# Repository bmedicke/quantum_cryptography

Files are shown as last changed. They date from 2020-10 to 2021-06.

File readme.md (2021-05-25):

quantum cryptography logo

Demonstration of **quantum-cryptography-based one-time pad communication** via<br>the **BB84 algorithm** using a non-single photon source.



[project progress](#project-progress) | [contributors](#contributors) | [repository structure](#repository-structure) | [frequently asked questions](#frequently-asked-questions)

---

## project progress

Kanban Boards:  [**Everyone**](https://github.com/bmedicke/quantum_cryptography/projects/1?fullscreen=true), [Ben](https://github.com/bmedicke/quantum_cryptography/projects/1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), [Ferdi](https://github.com/bmedicke/quantum_cryptography/projects/1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), [Manu](https://github.com/bmedicke/quantum_cryptography/projects/1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), [Niko](https://github.com/bmedicke/quantum_cryptography/projects/1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)





## contributors

| Author | GitHub profile | homepage |
|---|---|---|
| Benjamin Medicke | [bmedicke](https://github.com/bmedicke) | [benmedicke.com](https://benmedicke.com) |
| Ferdi Cevik | [Osomo3000](https://github.com/Osomo3000) | [cf-projects](http://cf-projects.net/) |
| Manuel Nagel | [namanuel](https://github.com/namanuel) | [namanuel.github.io](https://namanuel.github.io/) |
| Nikolai Benedikt | [nikobenedikt](https://github.com/nikobenedikt) | |

## repository structure

Here's a quick breakdown of what to find where in the repository:

* [Theory](markdown/theory.md) 💭 describes the the BB84 algorithm and required theory
* [Hardware](markdown/hardware.md) 🔭 collects information about which hardware was used and how to set it up
* [3D models](3d-models) 🏗️ holds printable components
* [Setup](markdown/setup.md) 🧑🏻‍💻 installation instructions for the software and required services
* [Notebooks](notebooks) 🪐 contains the actual JupyterLab Notebooks for Alice, Bob and Eve
* [Guidelines](markdown/guidelines.md) ✒️  coding and contribution guidelines
* [qcrypt docs](https://bmedicke.github.io/quantum_cryptography) 📜 documentation for the quantum crypto library

## frequently asked questions

**Why build some components instead of using the respective ThorLabs versions?**

Mainly to keep it open-source and reduce the size of the hardware setup. As an added bonus it lowers the cost and barrier of entry for anyone who is interested in replicating the project.

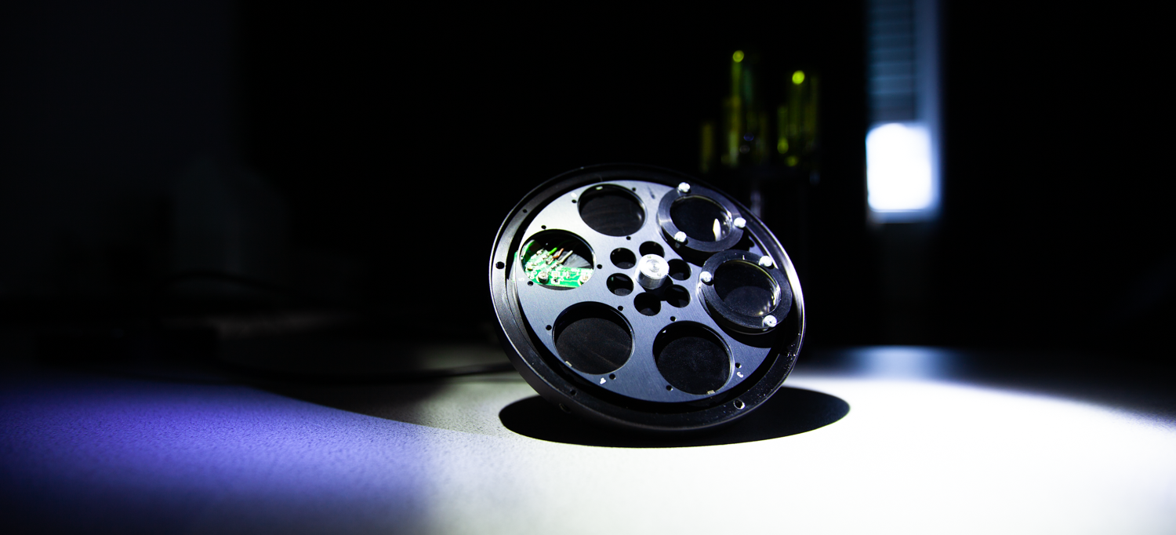
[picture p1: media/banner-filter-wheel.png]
filter wheel from ThorLabs
> 
> ThorLabs motorized filter wheel

**What hardware do I need to run this project?**

See [Hardware](markdown/hardware.md) for a list of required components and [3D models](3d-models) for printable parts.

**Why use JupyterLab Notebooks as a frontend?**

On one hand, JupyterLab provides an interactive, browser-based computing environment, which makes it easy to do exploratory coding.
On the other hand, different types of cells in a notebook allow code and markdown-based documentation to live in the same document.
We hope this makes it easier to follow both the code and BB84 protocol.

**Is Python 3.9 absolutely required?**

Yes. We make use of some of the [new features](https://docs.python.org/3/whatsnew/3.9.html).

**When running `pip install -r requirements.txt` it fails with `Building wheel for smbus (setup.py) ... error`.**

You are probably not on a Raspberry Pi with Raspbian (or a similar operating system). This is due to missing I2C. If you're just interested in seeing the notebooks and running some parts of them you can remove the smbus line from `requirements.txt`. You won't be able to use the quantum channel, of course.

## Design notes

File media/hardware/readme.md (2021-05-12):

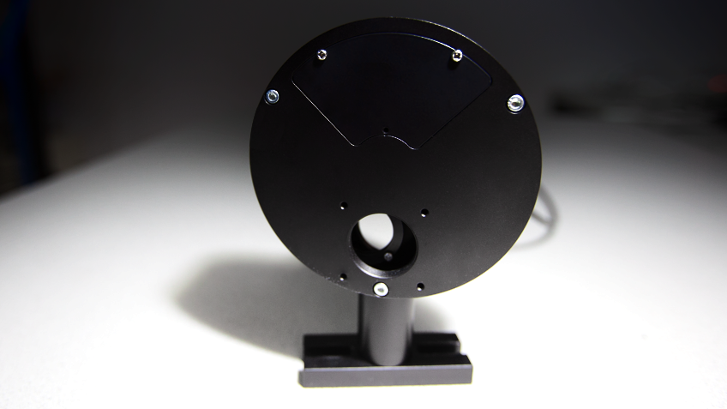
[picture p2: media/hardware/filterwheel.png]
ThorLabs filter wheel


> ThorLabs filter wheel

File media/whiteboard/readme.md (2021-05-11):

# whiteboard photos

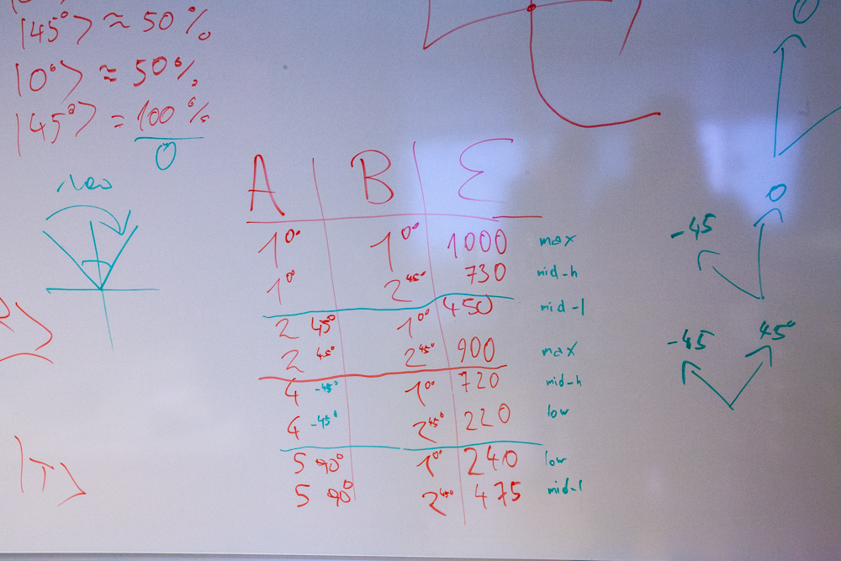
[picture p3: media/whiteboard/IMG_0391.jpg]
polarisation filter orientations


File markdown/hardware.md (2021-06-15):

# notes

## filter wheel polarization-orientation measurements

| Alice filter ID | Alice filter orientation | Bob filter ID | Bob filter orientation | beam intensity | classification |
| --- | --- | --- | --- | --- | --- |
| 1 | 0° | 1 | 0° | 1000 µW | max |
| 1 | 0° | 2 | 45° | 730 µW | mid-high |
| 2 | 45° | 1 | 0° | 450 µW | mid-low |
| 2 | 45° | 2 | 45° | 900 µW | max |
| 4 | -45° | 1 | 0° | 720 µW | mid-high |
| 4 | -45° | 2 | 45° | 220 µW | low |
| 5 | 90° | 1 | 0° | 240 µW | low |
| 5 | 90° | 2 | 45° | 475 µW | mid-low |

# Motor current setting
The motor voltage for the stepper driver is set at 0.31V. To increase the voltage you have to turn the screw on the stepper driver clockwise.

# KiCAD - Circuit diagram
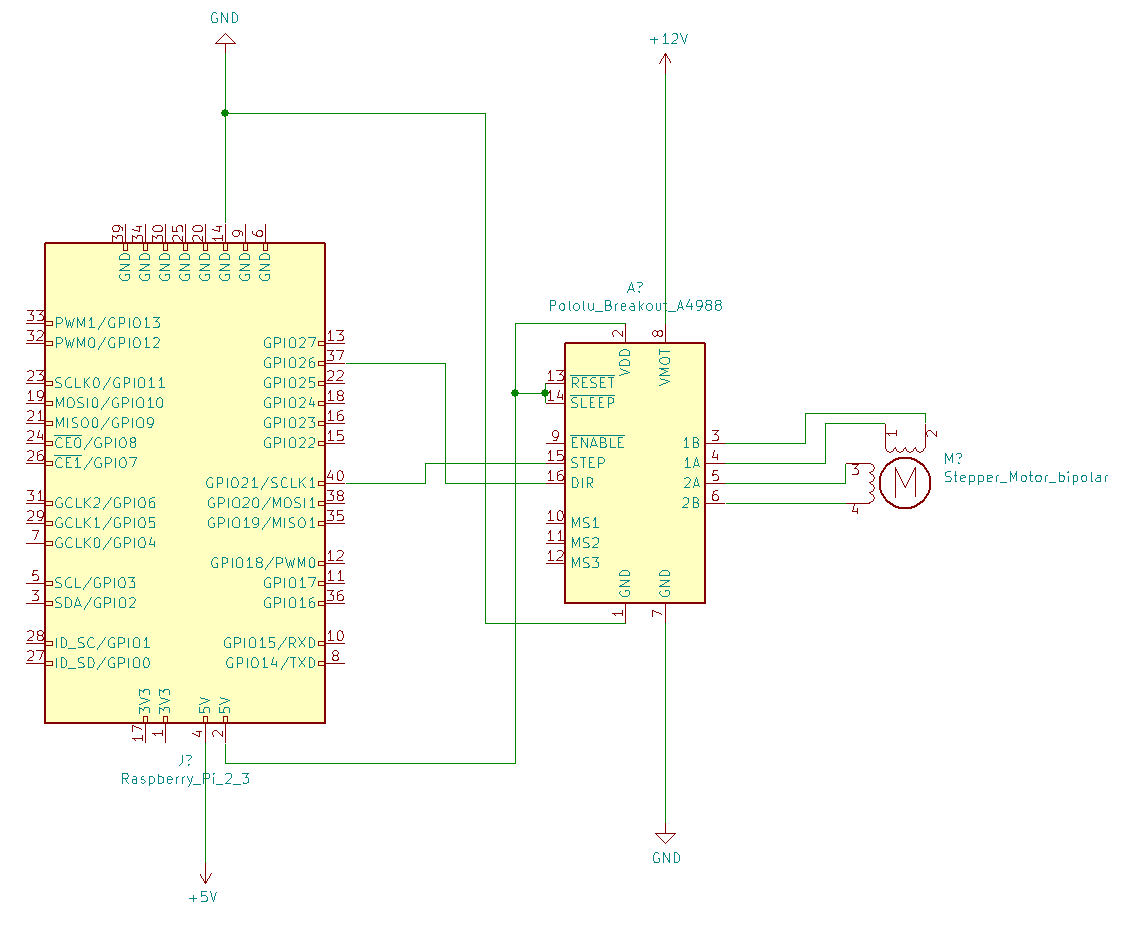
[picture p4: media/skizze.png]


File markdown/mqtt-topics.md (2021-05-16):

# MQTT topic overview

The main topic level is `quantum_cryptography`. All MQTT messages in this project start with it.
It has two sub-topics, which in turn have more granular topics:

* `clasiscal_channel`
  * All communication that is to happen over the classical channel according to the BB84 protocol.
* `quantum_channel`
  * For the simulation of the quantum channel (to use the project without hardware).
* `debug_channel`
  * A debug channel that can be used for arbitrary log messages.
  * **This data may not be used in the BB84 scheme.**

## the classical channel

* `alice`
  * `laser`
    * msg: `on`
    * msg: `off`
* `bob`
  * `light-sensor`
    * msg: `on`
    * msg: `off`

As an example: if Alice turns the laser on to send a bit she will send
the message-payload **`on`** over the channel `quantum_cryptography/classical_channel/alice/laser`.

**Do not use a leading `/`, it introduces an uneccessary empty level.**

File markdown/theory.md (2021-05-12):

# quantum cryptography

<!-- vim-markdown-toc GFM -->

* [quantum key distribution](#quantum-key-distribution)
  * [BB84 protocol](#bb84-protocol)
    * [prerequisites Alice](#prerequisites-alice)
    * [prerequisites Bob](#prerequisites-bob)
    * [procedure of events](#procedure-of-events)
    * [consequences of eavesdropping](#consequences-of-eavesdropping)
* [sources and further reading](#sources-and-further-reading)

<!-- vim-markdown-toc -->

# quantum key distribution

Basic order of events:

1. generating a one time pad between Alice and Bob
2. then checking if anybody was eavesdropping

---

* after sharing the key a test is performed:
  * if anybody was listening the key is discarded
  * if not they now have a new key to communicate with
* the reason why this works is because **any measurement on a quantum object leaves a trace**
  * it is impossible to read information traveling over a quantum channel without perturbing it

## BB84 protocol

* this scheme can use any quantum object with a two value observable
* in practice the quantum object is the **polarization of a photon** (quantum optics)

### prerequisites Alice

Alice has a source to generate photons with four possible polarizations:

1. **H**, horizontal
2. **V**, vertical
3. **L**, left
4. **R**, right

The four polarizations can be grouped into two sets.
The **HV set** is located along the X and Y axis. The **LR set** 45 degrees rotated from that.

> polarizations.jpg
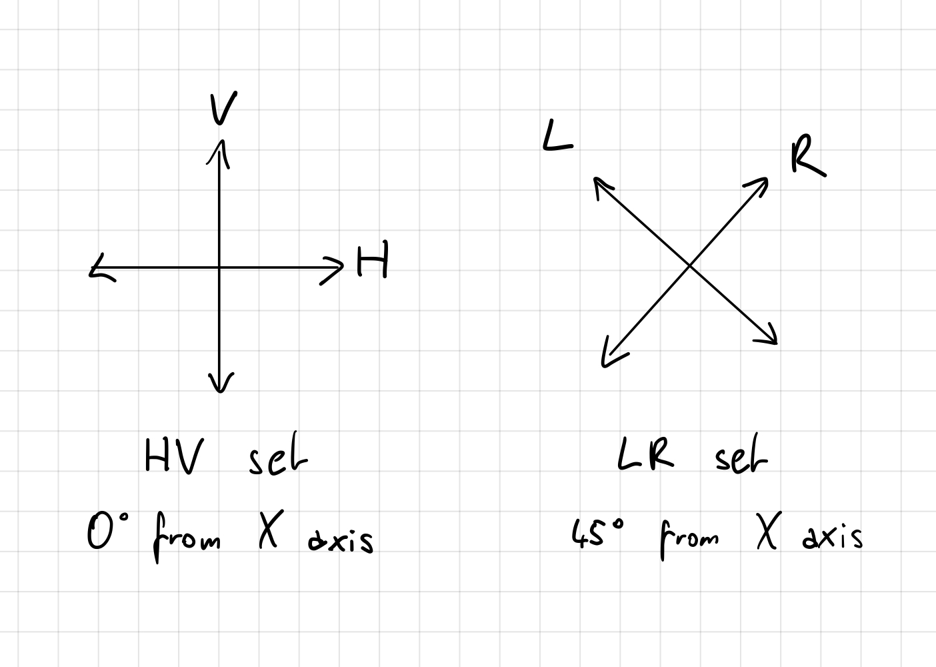
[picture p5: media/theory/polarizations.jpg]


### prerequisites Bob

Bob has two polarization beam splitters with which he analyzes photons sent by Alice. One oriented at 0 degrees (vertical) and one at 45 degrees (diagonal).

The **vertical beam splitter** can analyze photons of the HV set. The **diagonal beam splitter** can analyze photons of the LR set.

Each beam splitter can produce two values.
* Vertical beam splitter:
  1. **H**, horizontal
  2. **V**, vertical
* Diagonal beam splitter:
  1. **L**, left
  2. **R**, right

> beam-splitter.jpg
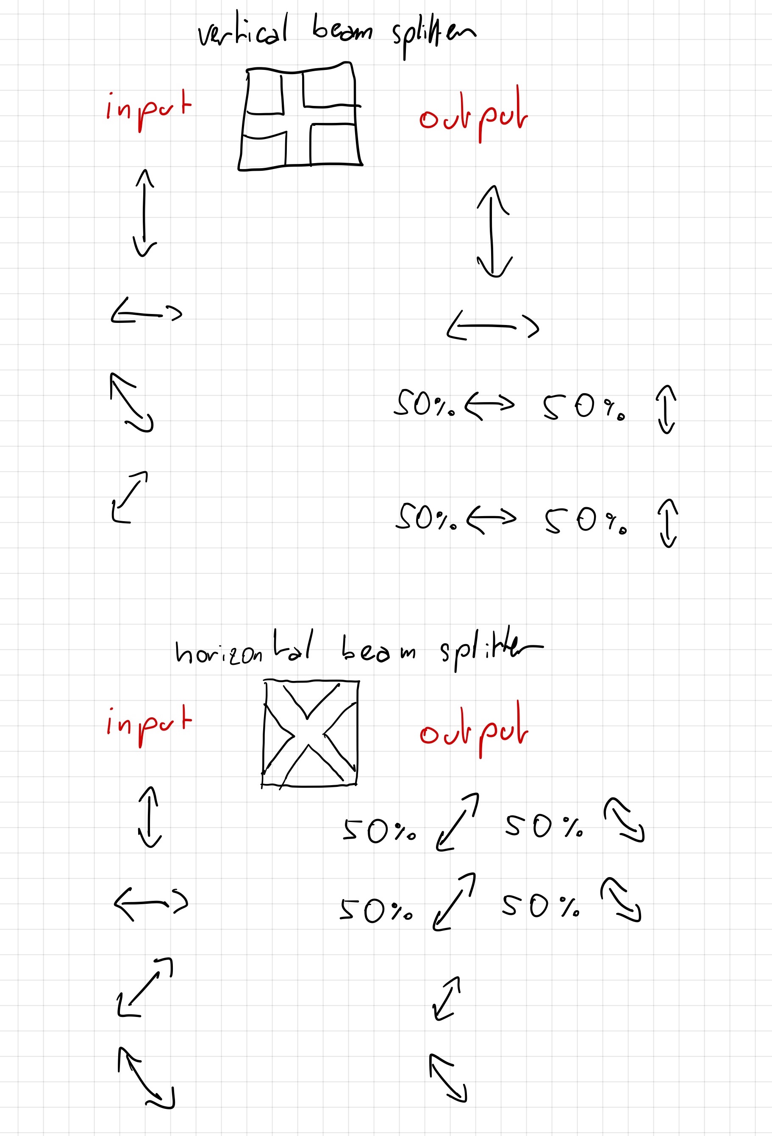
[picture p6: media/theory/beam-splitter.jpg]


To obtain the original value of a photon (without fail) the orientations of Alice and Bob have to match up. Some examples:

* inputting H into the vertical beam splitter will always return H (match)
* inputting V into the vertical beam splitter will always return V (match)
* **inputting L or R into the vertical beam splitter will return a random value (H or V, mismatch)**

### procedure of events

For each (potential) bit of the key the following happens:

* Alice generates a randomly polarized photon (H, V, L or R) and publicly sends it to Bob
* Bob choses a random beam splitter to analyze the photon with
  * if Bob chose the correct beam splitter: he obtains the original value
  * if Bob chose the wrong beam splitter: he obtains a random value
* Bob saves the orientation of the beam splitter and the resulting value 
  * of which he still does not know if it's meaningful
  * there's a 50% chance it's just a random value due to orientation mismatch

After sending a bunch of photons we move on to the next step: **reconciliation**.

* Bob publicly announces all his chosen beam splitter orientations
* Alice publicly replies which were correct
* They both drop all the values where Bob chose wrong
* They now hold the key (which consists of all values where Bob chose correctly)

### consequences of eavesdropping

If Eve intercepts a photon to measure it, Bob will not receive it and thus will not use it in the key.
Alternatively, Eve can retransmit a photon, but **Bob can detect this by sacrifing some
Bits of the key and publicly sending them back to Alice!**

_This is where the quantum nature of the transmission medium kicks in:_

* Eve does not know the correct orientation (vertical or diagonal) and thus has to guess
  * if Eve guesses correctly she has no problem
    * the orientations match up and Bob will get the correct value
  * if Eve guesses wrong there is a 50% chance that Bob will receive the wrong value
    * if Bob randomly chooses this Bit to sacrifice (and send it back to Alice) she has a problem indeed
* **Alice sees that Bob sent back a wrong value despite the correct orientation! The key cannot be trusted!**
  * any one Bit being wrong when eavesdropped will happen in about 25% of the cases
    * 50% chance that Eve chooses the wrong orientation set and 50% chance of that for a wrong value

This entire scheme is based on the fact that you can not find out the basis of polarization of a single photon.

---

A couple of example scenarios:

> eve.jpg
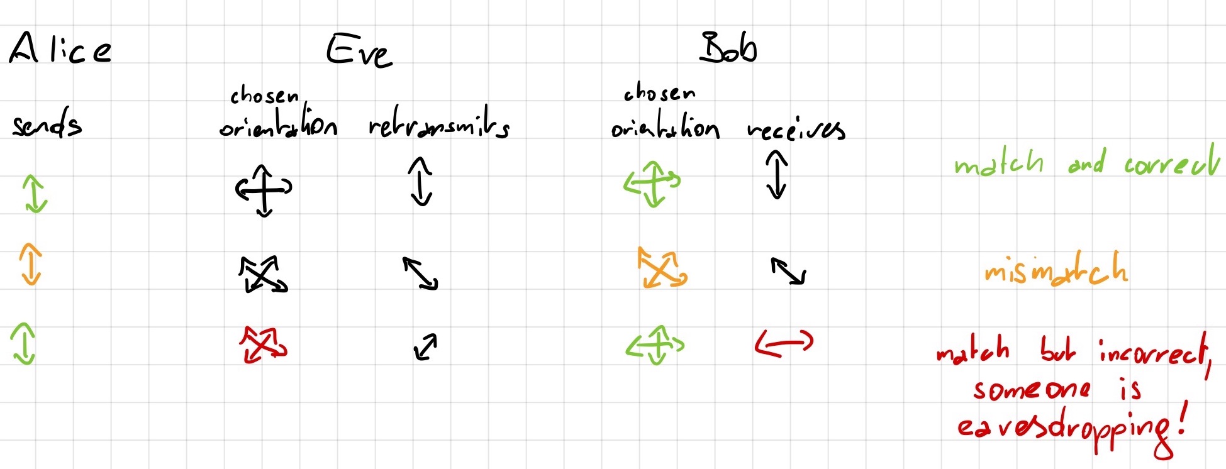
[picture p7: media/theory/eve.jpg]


* To keep it simple Alice always send `V`.
* In the first case Eve and Bob select a vertical splitter, eavesdropping takes place but is not detected.
* In the second case Alice and Bob have an orientation mismatch, the value is discarded.
  * Eve does not matter.
* In the third case Bob chose the correct and Eve the wrong orientation.
  * Eve is unlucky and the result is `H` instead of `V`.
  * Bob and Alice chose the same orientation but they still got differing values!
    * If Bob sacrifices this Bit and sends it to Alice they immediately know someone was eavesdropping.

# sources and further reading

* https://en.wikipedia.org/wiki/No-cloning_theorem

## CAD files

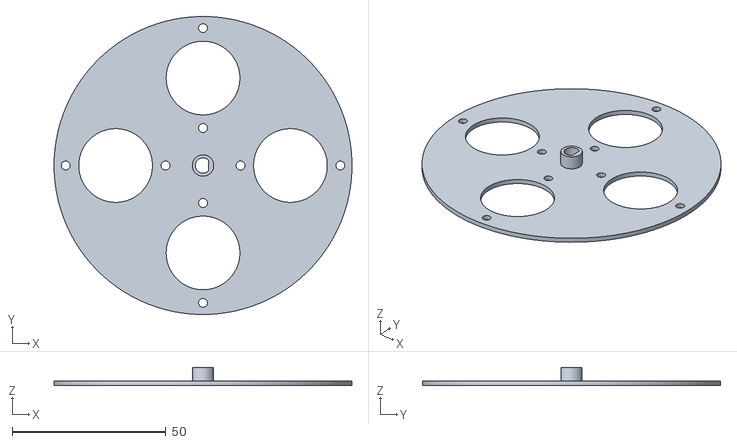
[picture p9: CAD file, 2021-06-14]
3d-models/stl/filterwheel v7.stl
97.0 x 97.0 x 6.00

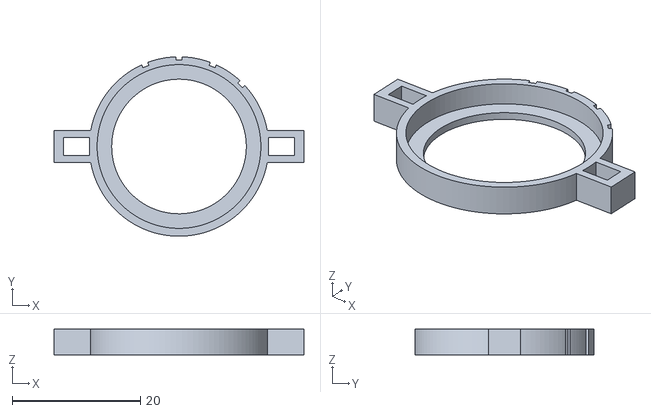
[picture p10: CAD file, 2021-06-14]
3d-models/stl/filter holder v6.stl
39.0 x 28.0 x 4.00

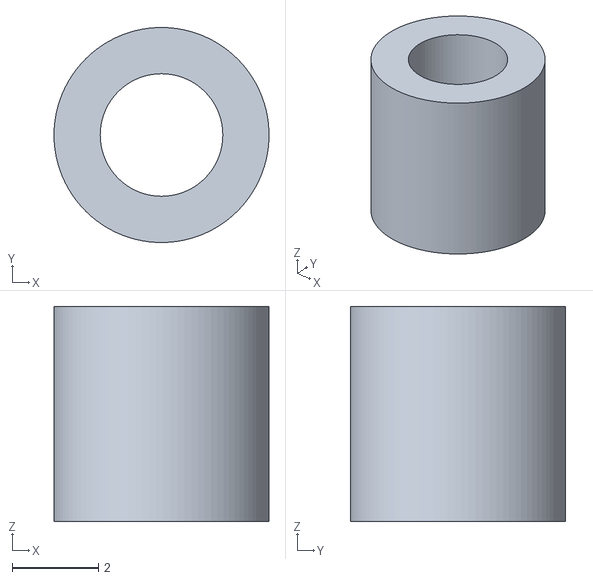
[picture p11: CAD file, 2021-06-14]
3d-models/stl/female screw v9.stl
5.00 x 5.00 x 5.00

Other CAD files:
3d-models/fusion/female screw v9.f3d
3d-models/fusion/filter holder v6.f3d
3d-models/fusion/filterwheel v7.f3d

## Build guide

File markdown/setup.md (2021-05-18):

# setup instructions

<!-- vim-markdown-toc GFM -->

* [environment](#environment)
* [Raspberry Pis](#raspberry-pis)
  * [Alice, Bob & Eve](#alice-bob--eve)
    * [Python 3](#python-3)
    * [cloning and initial setup](#cloning-and-initial-setup)
    * [starting the notebook](#starting-the-notebook)
  * [Alice](#alice)
    * [Docker & MQTT broker](#docker--mqtt-broker)
* [configuring the code formatter](#configuring-the-code-formatter)
* [configuring shortcuts](#configuring-shortcuts)
* [more JupyterLab extensions](#more-jupyterlab-extensions)
* [used libraries](#used-libraries)

<!-- vim-markdown-toc -->

## environment

* Rasbperry Pis running Raspbian
* Python  ≥3.9 (required for type hinting)
  * highly recommended: a virtual environment (like [venv](https://docs.python.org/3/library/venv.html))
* [JupyterLab](https://jupyter.org/) for running the notebooks
* an MQTT broker running in Docker

## Raspberry Pis

### Alice, Bob & Eve

#### Python 3

```sh
# check current Python version:
python3 --version # we need at least 3.9.

# build a newer Python version from source.
sudo apt update
sudo apt install build-essential zlib1g-dev libncurses5-dev libgdbm-dev libssl-dev libffi-dev libsqlite3-dev

wget https://www.python.org/ftp/python/3.9.5/Python-3.9.5.tgz # or newer.
tar -xf Python-* && cd Python-*/

# these steps might take a while.
./configure --enable-optimizations && make -j 5 # ~ number of cores +1.
sudo make altinstall # altinstall leaves the original install alone.

# check if it worked:
python3.9 --version
python3.9 -c 'import ssl;print(ssl.OPENSSL_VERSION)'
```

#### cloning and initial setup

```sh
# clone the repo:
git clone 'git@github.com:bmedicke/quantum_cryptography.git' # or via https.

# switch to the repo folder:
cd quantum_cryptography

# create a virtual Python environment with the new Python:
python3.9 -m venv env

# activate the virtual environment.
source env/bin/activate
  # while working in an activated virtual environment you can
  # simply use `python` and `pip` and  skip the postfixes.

# install requirements.
pip install wheel
pip install -r requirements.txt

# enable the I2C interface for the relay shield:
sudo raspi-config
  # Interfacing options → I2C → yes.
```

#### starting the notebook

```sh
# activate the virtual environment if its not still active.
source env/bin/activate # you can deactivate the venv with: deactivate
jupyter-lab --ip=0.0.0.0 --no-browser notebooks/ # start JupyterLab.
  # the first flag binds the programm to all network interfaces so we
  # can connect to the raspberry pi via its public IP address.
  # the second flag prevents a browser from popping up.

# now visit the displayed URL with the public IP address
# from any browser running on a device in the same network.
```

All required libraries are installed into the virtual environment.<br>
**You have to activate the virtual environment before starting JupyterLab.**

### Alice

#### Docker & MQTT broker

```sh
# install docker:
curl -fsSL https://get.docker.com | sh

# install docker-compose outside of venv:
sudo pip3 install docker-compose

# start the MQTT broker:
sudo docker-compose up -d

# check if it's running:
sudo docker-compose ps

# to stop it:
sudo docker-compose down
```

## configuring the code formatter

Set the default code formatter to black:

*Settings* → *Advanced Code Formatter* → *Jupyterlab Code Formatter* → *User Preferences*

```json
{
    "preferences": {
        "default_formatter": {
            "python": "black"
        }
    },
    "black": {
         "line_length": 79
    }
}
```

## configuring shortcuts

```json
{
  "shortcuts": [
    {
      "command": "notebook:run-cell",
      "keys": [
        ";"
      ],
      "selector": ".jp-Notebook:focus"
    },
    {
      "command": "kernelmenu:restart-and-clear",
      "keys": [
        "Ctrl L"
      ],
      "selector": ".jp-Notebook:focus"
    }
  ]
}

```

## more JupyterLab extensions

```sh
# get a newer nodejs version for the extensions:
curl -fsSL https://deb.nodesource.com/setup_16.x | sudo -E bash -
sudo apt install nodejs -y

# Git:
pip install --upgrade jupyterlab jupyterlab-git
jupyter labextension install @jupyterlab/git

# Spellchecker:
jupyter labextension install @ijmbarr/jupyterlab_spellchecker

# Vim:
jupyter labextension install @axlair/jupyterlab_vim
```

## used libraries

* [jupyterlab_code_formatter](https://github.com/ryantam626/jupyterlab_code_formatter)
  * and [black](https://github.com/psf/black) as a formatter
* [paho-mqtt](https://pypi.org/project/paho-mqtt/)
* [seeed-studio-relay-board](https://github.com/johnwargo/seeed-studio-relay-board)
  * library to control the seeed relay hat
  * updated version: [seeed-studio-relay-v2](https://github.com/johnwargo/seeed-studio-relay-v2)
    * supports stacked hats 🎩
  * [smbus](https://pypi.org/project/smbus/)
* [ipywidgets](https://github.com/jupyter-widgets/ipywidgets)

Installation without `requirements.txt`:

```sh
pip install paho-mqtt jupyterlab black jupyterlab-code-formatter ipywidgets
pip install smbus
```

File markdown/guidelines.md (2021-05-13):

# coding guidelines

* adhere to [PEP8](https://www.python.org/dev/peps/pep-0008/)
* use `black --line-length=79`

You can use an automated code formatter in JupyterLab, see: [Setup](setup.md) for instructions.

# contribution guidelines

Before git-adding changes to a JupyterLab Notebook click: `Kernel` → `Restart and Clear All Outputs` followed by the button `Format notebook`.

---

When pair-programming trail the commit message with:<br>
`Co-authored-by: Name <name@example.com>`.

See [Creating co-authored commits on GitHub](https://docs.github.com/en/github/committing-changes-to-your-project/creating-a-commit-with-multiple-authors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) for details.

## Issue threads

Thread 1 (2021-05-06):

get missing hardware

bmedicke, 2021-05-06:
- [x] ❗ router/tethering solution
- [x] 3.5mm cinch jacks
- [x] PC power supply
- [x] SD cards for the Raspberry Pis
- [x] micro HDMI to HDMI cable for the Raspberry Pis
- [x] get endstop or reed sensors for #8
- [x] motor for HeNe laser shutter #7

Closed 2021-05-18.

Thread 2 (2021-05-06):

control laser via relay shield

bmedicke, 2021-05-06:
via [johnwargo/seeed-studio-relay-board](https://github.com/johnwargo/seeed-studio-relay-board) or
[johnwargo/seeed-studio-relay-v2](https://github.com/johnwargo/seeed-studio-relay-v2)
see [setup.md](../blob/main/markdown/setup.md)

Closed 2021-05-13.

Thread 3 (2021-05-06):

build filter wheel adapter

bmedicke, 2021-05-06:

namanuel, 2021-05-12:
first prototype was made with cardboard

namanuel, 2021-05-12:
Ferdi printed a filterwheel to test reed sensoren (magnets are too big, but it works!)

namanuel, 2021-05-12:
we want to use reed sensores if possible to get the current position and set a start point

if it does not work, we use an endstop to get a start point

Closed 2021-06-13.

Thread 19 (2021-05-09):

evaluate JupyterLab as alternative to Jupyter Notebook

bmedicke, 2021-05-09:
- [x] make sure all notebooks from [bmedicke/amalthea](https://github.com/bmedicke/amalthea) are working with JupyterLab as well
- [x] test MQTT (paho) [proof of concept](https://github.com/bmedicke/amalthea/tree/main/notebooks/demos)
~~test AMQT (pika)~~
- [x] test JupyterLab on Raspberry Pi
- [x] add instructions
- [x] clean up and update `requirements.txt`

bmedicke, 2021-05-09:
So far I can't get `%matplotlib widget` to work, it fails with: `Error displaying widget: model not found`

bmedicke, 2021-05-09:
> So far I can't get `%matplotlib widget` to work, it fails with: `Error displaying widget: model not found`

fixed by: `jupyter labextension install @jupyter-widgets/jupyterlab-manager jupyter-matplotlib`

bmedicke, 2021-05-09:
samples for mqtt with docker: https://github.com/bmedicke?tab=repositories&q=mqtt

bmedicke, 2021-05-09:
receive in notebook (JupyterLab) via paho:

**cell 1 (setup & connection)**

```python
server = "broker.emqx.io"

import paho.mqtt.client as mqtt

# The callback for when the client receives a CONNACK response from the server.
def on_connect(client, userdata, flags, rc):
    print("Connected with result code "+str(rc))

    # Subscribing in on_connect() means that if we lose the connection and
    # reconnect then subscriptions will be renewed.
    client.subscribe("test")

# The callback for when a PUBLISH message is received from the server.
def on_message(client, userdata, msg):
    print(msg.topic+" "+str(msg.payload))

client = mqtt.Client()
client.on_connect = on_connect
client.on_message = on_message

client.connect(server, 1883, 60)

# Blocking call that processes network traffic, dispatches callbacks and
# handles reconnecting.
# Other loop*() functions are available that give a threaded interface and a
# manual interface.
```

**cell 2 (keeps running)**

```python
client.loop_forever()
```
---

send via mosquitto:

```sh
mosquitto_pub -h broker.emqx.io  --topic 'test' --message 'test'
```
---

*works great*

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

bmedicke, 2021-05-09:
# mosquitto aliases

```sh
alias sub="mosquitto_sub -u admin -P admin -v --topic 'lights/light1/lumen'"
alias pub="mosquitto_pub -u admin -P admin --topic 'lights/light1/lumen'"
alias long="mosquitto_pub -u admin -P admin -l --topic 'lights/light1/lumen'"
alias retain="mosquitto_pub -u admin -P admin -l --topic 'lights/light1/lumen' --retain"
alias will="mosquitto_pub -u admin -P admin --will-retain --will-topic 'lights/light1/lumen' --will-payload '0' -l --topic 'lights/light1/lumen'"
alias cl="mosquitto_pub -u admin -P admin --topic lights/light1/lumen --message '' --retain"
```

Closed 2021-05-09.

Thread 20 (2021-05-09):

setup an MQTT broker

bmedicke, 2021-05-09:
for the cross-notebook communication

- [x] run it on Alice or Bob?
    Alice
- [x] create docker container
- [x] test it on a Raspberry Pi

Closed 2021-05-10.

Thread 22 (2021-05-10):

try to switch out `smbus` for `smbus2`

bmedicke, 2021-05-10:
it should be a drop in replacement

Closed 2021-05-10.

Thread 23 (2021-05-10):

add photo of filter wheels (with labels showing orientation)

bmedicke, 2021-05-10:

bmedicke, 2021-05-12:
i think this is the wrong picture for this issue (no filters visible, no labels)

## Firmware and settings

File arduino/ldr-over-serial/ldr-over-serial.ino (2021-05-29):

// read values from light dependant resistors
// and send them over the serial port:

int const BAUD = 9600;
int const LDR_PIN_HOR = A1;
int const LRD_PIN_VER = A3;
int const DELAY = 100; // in milliseconds.

int resistance_horizontal = 0;
int resistance_vertical = 0;

void setup() {
  Serial.begin(BAUD);
}

void loop() {  
  resistance_horizontal = analogRead(LDR_PIN_HOR);
  resistance_vertical = analogRead(LRD_PIN_VER);
  
  Serial.println(String(resistance_horizontal) + ",\t" + String(resistance_vertical));
  
  delay(DELAY);
}

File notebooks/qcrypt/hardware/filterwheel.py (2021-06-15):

# standard libraries:
import time
import logging
import enum

# third party:
import paho.mqtt.client as mqtt

try:
    import RPi.GPIO as GPIO

    HARDWARE_IMPORTS = True
except ModuleNotFoundError as exception:
    print(f"{type(exception).__name__}: {exception}")
    HARDWARE_IMPORTS = False


class Orientation(enum.IntEnum):
    LEFT = 0  # -45°.
    VERTICAL = 1  # 0°.
    RIGHT = 2  # 45°.
    HORIZONTAL = 3  # 90°.


class Filterwheel:

    # executed at import:
    # logging
    logger = logging.getLogger("__Filterwheel__")
    formatter = logging.Formatter("%(asctime)s: %(levelname)s - %(message)s")
    streamhandler = logging.StreamHandler()
    filehandler = logging.FileHandler(filename="filterwheel.log", mode="a")
    streamhandler.setFormatter(formatter)
    filehandler.setFormatter(formatter)
    logger.addHandler(streamhandler)
    logger.addHandler(filehandler)

    def __init__(
        self,
        username="Alice",
        dir_pin=26,
        step_pin=21,
        delay_in_seconds=0.0025,
        mqtt_broker_ip="localhost",
        log_level="INFO",
    ):

        """
        Construct a Filterwheel
        """
        self.username = username
        self.dir_pin = dir_pin
        self.step_pin = step_pin
        self.delay_in_seconds = delay_in_seconds
        self.mqtt_broker_ip = mqtt_broker_ip
        self.log_level = log_level
        self.orientation = Orientation.VERTICAL

        self.logger.setLevel(log_level)

        if HARDWARE_IMPORTS:
            GPIO.setwarnings(False)
            GPIO.setmode(GPIO.BCM)
            GPIO.setup(dir_pin, GPIO.OUT)
            GPIO.setup(step_pin, GPIO.OUT)

        else:
            self.logger.error(
                "failed to import required hardware modules: "
                "### Continuing in simulation mode ... ###"
            )

    def rotate_to(self, orientation):
        start = self.orientation
        stop = orientation
        print(start, "-->", stop)
        if start == stop:
            print("no need to rotate")
        elif abs(start - stop) == 2:
            print("rotating 180°")
            self._rotate(clockwise=True, steps=100)
        else:
            diff = abs(start - stop)
            if diff == 1:
                if start > stop:
                    print("rotating right")
                    self._rotate(clockwise=True)
                else:
                    print("rotating left")
                    self._rotate(clockwise=False)
            if diff == 3:
                if start < stop:
                    print("rotating right")
                    self._rotate(clockwise=True)
                else:
                    print("rotating left")
                    self._rotate(clockwise=False)
                    
        self.orientation = orientation

    def _rotate(self, clockwise=True, steps=50):
        """
        Rotates in "dir" direction "steps" time
        """

        if HARDWARE_IMPORTS:
            GPIO.output(self.dir_pin, clockwise)

            for x in range(steps):
                GPIO.output(self.step_pin, GPIO.HIGH)
                time.sleep(self.delay_in_seconds)
                GPIO.output(self.step_pin, GPIO.LOW)
                time.sleep(self.delay_in_seconds)

        if clockwise:
            direction = "clockwise"
        else:
            direction = "counter-clockwise"

        self.logger.info(f"{self.username} rotating {steps} steps {direction}")

    def on_connect(self, client, userdata, flags, rc):
        """
        called on MQTT connection
        """
        self.logger.info(f"mqtt: {self.username} connected")

    def on_disconnect(self, client, userdata, rc):
        """
        called on MQTT disconnection
        """
        self.logger.warning(f"mqtt: {self.username} disconnected")

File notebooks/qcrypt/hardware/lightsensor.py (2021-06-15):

# standard libraries:
import time
import logging
import serial

# third party:
import paho.mqtt.client as mqtt

try:
    import RPi.GPIO as GPIO

    HARDWARE_IMPORTS = True
except ModuleNotFoundError as exception:
    print(f"{type(exception).__name__}: {exception}")
    HARDWARE_IMPORTS = False


class Lightsensor:
    logger = logging.getLogger("__Lightsensor__")
    formatter = logging.Formatter("%(asctime)s: %(levelname)s - %(message)s")
    streamhandler = logging.StreamHandler()
    filehandler = logging.FileHandler(filename="lightsensor.log", mode="a")
    streamhandler.setFormatter(formatter)
    filehandler.setFormatter(formatter)
    logger.addHandler(streamhandler)
    logger.addHandler(filehandler)

    def __init__(
        self,
        device="/dev/ttyACM0",
        # mqtt_broker_ip="localhost",
        log_level="INFO",
        baud_rate=9600,
        timeout=1,
    ):
        self.device = device
        # self.mqtt_broker_ip = mqtt_broker_ip
        self.log_level = log_level
        self.baud_rate = baud_rate
        self.timeout = timeout
        self.logger.setLevel(log_level)
        self.ser = self.getSerialConnection()

    def getSerialConnection(self):
        try:
            print("establishing connection to lightsensor ..")
            return serial.Serial(
                self.device, self.baud_rate, timeout=self.timeout
            )
        except serial.SerialException:
            self.logger.error("Serial connection could not be established")

    # resets buffer and waits until it is filled up 30 and prints
    def getValuesArray(self):
        self.ser.reset_input_buffer()
        while self.ser.in_waiting < 30:
            pass
        print("ser_in_waiting: " + str(self.ser.in_waiting))
        print(self.ser.readline().decode("utf-8").split(",\t"))
        return self.ser.readline().decode("utf-8").split(",\t")

    def getHighLow(self):
        values = self.getValuesArray()
        if len(values) < 0:
            return False

        high_low = []
        print(values)
        if len(values) == 2:
            try:
                for i in range(len(values)):
                    if int(values[i]) < 100:
                        high_low.append("High")
                    elif int(values[i]) >= 100:
                        high_low.append("Low")
            except ValueError:
                print(ValueError)
                return False

        return high_low

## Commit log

2021-05-06 switch to english, clean up formatting
2021-05-06 add software.md and add seeed relay lib
2021-05-06 add filter measurements pic
2021-05-07 add relay lib description
2021-05-07 call it kanban board, closes #11
2021-05-07 use fullscreen link for kanban board
2021-05-07 add current hardware setup section
2021-05-07 add seeed lib from: johnwargo/seeed-studio-relay-board
2021-05-07 manually install wheel
2021-05-07 mention I2C interface
2021-05-07 explain I2C req.
2021-05-09 switch to JupyterLab
2021-05-11 Added filterwheel picture closes #23
2021-05-13 fix relaytest script
2021-05-13 write basic laser controls
2021-05-13 add test notebook for laser controls
2021-05-13 default to relay 1
2021-05-13 add button to fire laser
2021-05-16 remove print statement
2021-05-16 disable print statements for simple on/offs
2021-05-16 add ability to config broker
    [laser.py]
2021-05-16 make laser a class
2021-05-24 switch to read-the-docs theme
2021-05-24 remove debug print, add ending newline
2021-05-24 add laser documentation
2021-05-25 add import guard on missing hardware imports
    [laser.py]
2021-05-29 pylint laser lib
2021-06-13 create filterwheel library
    Co-authored by: Benjamin Medicke <bmedicke@gmail.com>
    closes #46
2021-06-13 instantiate and test laserlibrary
2021-06-14 fix rotate(), clean up constructor
    [filterwheel.py]
2021-06-14 use filterwheel library
2021-06-14 connect to alice's mqtt broker, user filterwheel
2021-06-14 add light sensor scaffold
2021-06-14 add 3d-models
    [female screw v9.f3d, female screw v9.stl, filter holder v6.f3d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]
2021-06-14 switch broker to emqx.io
2021-06-14 specify serial error message
    [lightsensor.py]
2021-06-15 create laser instance
2021-06-15 add buttons for filterwheel
2021-06-15 turn filterwheel accordingly
2021-06-15 insert main quantum logic
2021-06-15 fix second channel laser bug
2021-06-15 save sensor values to list
2021-06-15 fix duplicate print
